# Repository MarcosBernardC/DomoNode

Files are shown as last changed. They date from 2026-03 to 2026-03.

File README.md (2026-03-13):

# DomoNode 🏠⚡






**DomoNode** es un ecosistema IoT de grado industrial diseñado bajo una metodología de desarrollo iterativo. El proyecto escala desde el control de registros en silicio hasta la visualización de datos en la nube, priorizando la eficiencia energética y la documentación técnica rigurosa.

---

## 🏗️ Metodología de Desarrollo (MVP Iterativo)

El progreso del proyecto se documenta a través de reportes técnicos generados en **LuaLaTeX**, vinculando cada iteración con una capa del modelo de sistemas:

### [Iteración 01: System Heartbeat](./research/build/01_heartbeat.pdf) 📄

- **Foco:** Capa 0 (Hardware Core).
- **Hito:** Validación de estabilidad del oscilador interno y secuencia de arranque segura.
- **Resultado:** Consumo optimizado mediante configuración MFINTOSC a 500kHz.
- **🎥 [Ver Demostración](https://youtu.be/Y8ERYFn19mU)**

### [Iteración 02: UART Timing & Telemetry](./research/build/02_uart.pdf) 📄

- **Foco:** Capa 1 y 2 (Física y Enlace).
- **Hito:** Implementación de telemetría serial con error de baudaje del 0.16%.
- **Resultado:** Comunicación robusta a 9600 bps para transmisión de tramas de sensores.
- **🎥 [Ver Demostración](https://youtu.be/vGGgzFn22VY?si=uIu9ADjewPjObTmR)**

---

## 🛠️ Stack Tecnológico

| Dominio | Tecnologías |
| :--- | :--- |
| **Firmware** | Microchip XC8, PIC16F1939, Embedded C |
| **Hardware** | KiCad (Schematic), Proteus/PICSimLab (Simulación) |
| **Infraestructura** | Supabase (PostgreSQL), Koyeb (Deployment) |
| **Documentación** | LuaLaTeX, Inkscape (Vector Graphics) |

---

## 🚀 Alcance del Proyecto

1. **Eficiencia en el Edge:** Algoritmos de bajo consumo para nodos autónomos.
2. **Integración Cloud:** Pipeline de datos real-time desde el microcontrolador al dashboard.
3. **Documentación Técnica:** Manuales de ingeniería con estándares DIN-Minimal.

## Licencia 📄

Este proyecto está bajo la licencia **Attribution-NonCommercial-ShareAlike 4.0 International (CC BY-NC-SA 4.0)**.
Desarrollado por **Marcos Bernard Calixto López**.

---

_Ingeniería Electrónica | Hardware-to-Cloud Integration_

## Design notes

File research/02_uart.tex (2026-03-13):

\documentclass[11pt,a4paper]{article}

% --- Paquetes de Idioma y Tipografía ---
\usepackage[spanish, es-tabla]{babel}
\usepackage{fontspec}
\usepackage{unicode-math}
\usepackage{graphicx}

% --- Layout y Estética ---
\usepackage{amsmath}
\usepackage{booktabs}
\usepackage{geometry}
\usepackage[table]{xcolor} 
\usepackage{microtype}
\usepackage{siunitx}
\usepackage{fancyhdr}
\usepackage{titlesec}
\usepackage{float}

% --- Definición de Colores ---
\definecolor{BLogicNavy}{HTML}{002E5D} 
\definecolor{IndustrialBlue}{HTML}{005EB8}
\definecolor{LightGray}{HTML}{E0E0E0}

% --- Configuración de Fuentes ---
\setmainfont{libertinusserif-regular.otf}[
    BoldFont = libertinusserif-bold.otf,
    ItalicFont = libertinusserif-italic.otf,
    BoldItalicFont = libertinusserif-bolditalic.otf
]
\setmathfont{STIXTwoMath-Regular.otf}
\setmonofont{lmmono10-regular.otf}

\geometry{top=3cm, bottom=3cm, left=2.5cm, right=2.5cm}

% --- Personalización de Títulos (Estética DIN-Minimal) ---
\titleformat{\section}
  {\color{BLogicNavy}\normalfont\Large\bfseries\scshape}
  {\thesection}{1em}{}[\titlerule]

\titleformat{\subsection}
  {\normalfont\large\bfseries}
  {\color{BLogicNavy}\textbullet\ \thesubsection}{1em}{}

% --- Definición de la Fase Actual ---
\newcommand{\faseactual}{MVP: Prototipado Iterativo} 

% --- Pie de Página ---
\pagestyle{fancy}
\fancyhf{}
\renewcommand{\headrulewidth}{0pt}
\renewcommand{\footrulewidth}{0.6pt} 

\fancyfoot[L]{\footnotesize \color{gray} \textbf{DOMONODE} $|$ \faseactual}
\fancyfoot[R]{\footnotesize \color{gray} Página \thepage}

% --- Metadatos PDF ---
\usepackage[pdfauthor={Marcos Bernard Calixto Lopez},
            pdftitle={DomoNode - Iteración 02: UART Timing Validation},
            pdfsubject={Ingeniería Electrónica - UART Analysis},
            pdfkeywords={IoT, PIC16F1939, UART, XC8, MVP},
            pdfstartview={FitH},
            colorlinks=true,
            linkcolor=BLogicNavy,
            urlcolor=IndustrialBlue]{hyperref}

% --- Ruta de búsqueda para imágenes y PDFs ---
\graphicspath{{research/assets/}{assets/}}

\begin{document}

% --- PORTADA DIN-INDUSTRIAL ---
\begin{titlepage}
    \hrule height 2pt
    \vspace{0.4cm}
    
    \begin{flushleft}
        \begin{minipage}[t]{0.60\textwidth}
            {\color{BLogicNavy}\Large\addfontfeatures{LetterSpace=15}\textbf{DOMONODE PROJECT}\par}
            \vspace{0.12cm}
            {\color{gray}\footnotesize\scshape Nodo IoT de Monitoreo Ambiental | Edge Intelligence}
        \end{minipage}
        \begin{minipage}[t]{0.39\textwidth}
            \raggedleft
            {\color{gray}\scriptsize 
            \textbf{FASE} \ $|$ \ \faseactual \\ 
            \textbf{ITERACIÓN} \ $|$ \ 02}
        \end{minipage}
    \end{flushleft}
    
    \vspace{5.5cm}

    \begin{flushleft}
        {\color{gray}\footnotesize\scshape Research \& Hardware Validation}\par
        \vspace{0.25cm}
        {\Huge\addfontfeatures{LetterSpace=2}\textbf{UART Timing \& Telemetry}\par}
        \vspace{0.4cm}
        {\color{BLogicNavy}\hrule height 1.8pt width 11cm} 
        \vspace{0.6cm}
        {\small\textsf{Validación de Capa de Enlace \ $|$ \ Optimización de Consumo}}
    \end{flushleft}

    \vfill

    \begin{flushleft}
        \begin{minipage}{0.5\textwidth}
            \hrule width 3cm
            \vspace{0.3cm}
            {\footnotesize\color{gray}\scshape Responsable del Proyecto}\\
            \vspace{0.15cm}
            \textbf{Marcos Bernard Calixto López}\\
            {\small Ingeniería Electrónica}
        \end{minipage}
    \end{flushleft}

    \vspace{1.5cm}
    
    \hrule height 0.6pt
    \vspace{0.2cm}
    \begin{minipage}[t]{0.65\textwidth}
        {\color{gray}\tiny \textcopyright \ 2026 Marcos Bernard Calixto López. \\ Algunos derechos reservados. Licencia CC BY-NC-SA 4.0.}
    \end{minipage}
    \begin{minipage}[t]{0.34\textwidth}
        \raggedleft
        {\color{gray}\footnotesize Santiago de Surco, \today}
    \end{minipage}
\end{titlepage}

\newpage

% --- CUERPO DEL DOCUMENTO ---

\section{Comunicación: Requerimientos de Telemetría}
Para la evolución del ecosistema \textbf{DomoNode}, se requiere establecer un canal de comunicación asíncrono robusto que permita el envío de tramas de sensores hacia una etapa de agregación. El reto técnico reside en mantener la integridad de los datos operando a una frecuencia de oscilación baja (\SI{500}{\kilo\hertz}) para maximizar la eficiencia energética.

\section{Planificación y Modelado}
En esta segunda iteración, el enfoque se desplaza de la señal de diagnóstico (\textit{Heartbeat}) hacia la \textbf{Capa de Enlace}. Se utiliza el generador de baudios de 16 bits para mitigar errores de cuantización.

\subsection{Análisis de Error ($F_{OSC} = \SI{500}{\kilo\hertz}$)}
Utilizando el modo \texttt{BRG16=1}, se valida matemáticamente la estabilidad a \SI{9600}{bps}:
\begin{equation}
BaudRate = \frac{\SI{500000}{}}{4 \cdot (12 + 1)} = \SI{9615.38}{bps} \implies \text{Error: } \SI{0.16}{\percent}
\end{equation}

\subsection{Asignación de Recursos de Hardware}
\begin{table}[H]
    \centering
    \caption{Especificaciones Técnicas - Iteración 02}
    \vspace{0.2cm}
    \begin{tabular}{@{}llll@{}}
        \toprule
        \textbf{Recurso} & \textbf{Función} & \textbf{Capa} & \textbf{Pin / Valor} \\
        \midrule
        UART TX      & Telemetría Serial   & \textbf{1} (Física) & RC6 (Pin 25) \\
        UART RX      & Comandos/Config     & \textbf{1} (Física) & RC7 (Pin 26) \\
        Baud Rate    & 9600 bps            & \textbf{2} (Enlace) & 0.16\% Error \\
        \bottomrule
    \end{tabular}
\end{table}

\section{Construcción y Validación en Protoboard}
Implementación física para corroborar el análisis matemático previo.

\subsection{Esquemático de Conexión Serial}
Se integra un conversor USB-TTL al nodo \textbf{DomoNode}. Se mantiene el LED de \textit{Heartbeat} en \textbf{RD7} como monitor de estado del sistema durante la transmisión de ráfagas UART.

\begin{figure}[H]
    \centering
    
    \caption{Diagrama de interconexión para validación de telemetría UART.}
    \label{fig:esquema_uart}
\end{figure}

\subsection{Pruebas de Campo e Integración}
El montaje en protoboard valida la ráfaga de datos cada \SI{60}{\second}. Se observa que a \SI{9600}{bps}, el tiempo de ocupación del bus es mínimo (\SI{12.5}{\milli\second}), lo que permite al \textbf{PIC16F1939} retornar a estados de bajo consumo rápidamente.

\begin{figure}[H]
    \centering
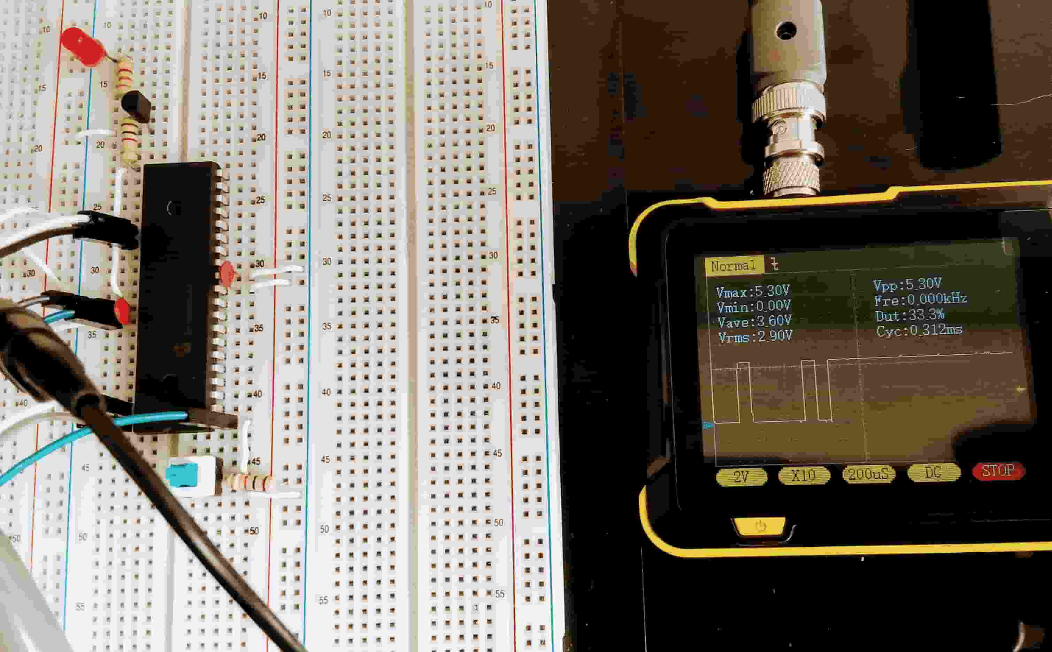
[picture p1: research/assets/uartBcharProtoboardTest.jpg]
    
    \caption{Prototipo físico DomoNode V2: Pruebas de comunicación serial.}
    \label{fig:protoboard_v2}
\end{figure}

\subsection{Resultados del Monitoreo Digital}
La validación del flujo de datos se realizó mediante el software de monitoreo industrial \textbf{HTerm} sobre la distribución \textbf{Fedora}. Se confirmó la recepción íntegra del testigo de transmisión (\textit{testigo 'B'}) con una periodicidad de \SI{1}{\second}.

\begin{figure}[H]
    \centering
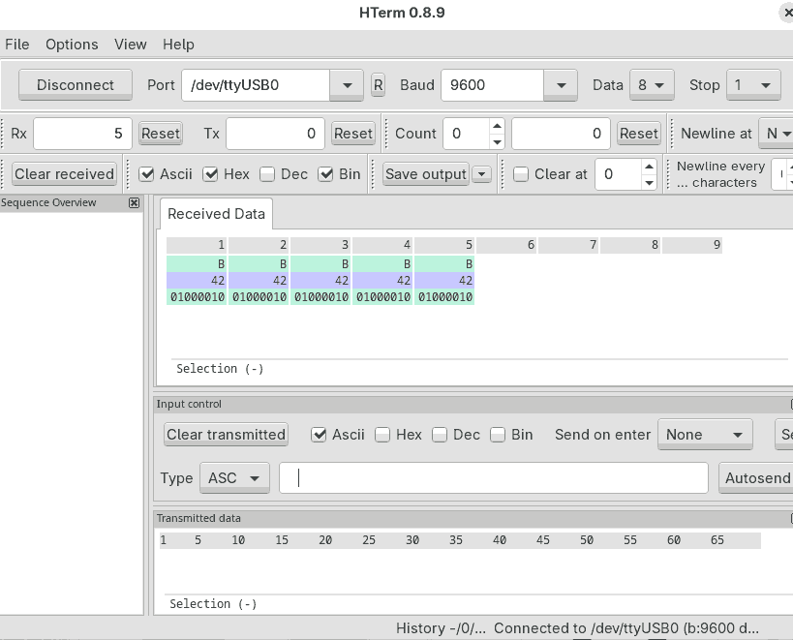
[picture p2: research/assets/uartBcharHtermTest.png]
    
    \caption{Monitoreo multiformato en HTerm: Validación del testigo de transmisión. Se observa la consistencia entre el carácter ASCII 'B', su valor hexadecimal (0x42) y su representación binaria, confirmando la estabilidad del baudaje a \SI{500}{\kilo\hertz}.}
    \label{fig:hterm_success}
\end{figure}

\vspace{0.3cm}
\noindent\textbf{Demostración en video:} 
\href{https://youtu.be/vGGgzFn22VY?si=uIu9ADjewPjObTmR}{DomoNode Iteración 02 - Validación UART \& Timing}

\section{Conclusiones de la Iteración 02}
La validación física confirma que la configuración de 16 bits del BRG permite una comunicación fiable incluso a frecuencias de reloj reducidas. 
\begin{itemize}
    \item \textbf{Resultado:} Error de baudaje dentro de los límites industriales ($<\SI{2}{\percent}$).
    \item \textbf{Próximo Paso:} Integración del sensor de temperatura/humedad para generar tramas de datos reales en la Iteración 03.
\end{itemize}

\end{document}

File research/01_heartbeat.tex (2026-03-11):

\documentclass[11pt,a4paper]{article}

% --- Paquetes de Idioma y Tipografía ---
\usepackage[spanish, es-tabla]{babel}
\usepackage{fontspec}
\usepackage{unicode-math}
\usepackage{graphicx}

% --- Layout y Estética ---
\usepackage{amsmath}
\usepackage{booktabs}
\usepackage{geometry}
\usepackage[table]{xcolor} 
\usepackage{microtype}
\usepackage{siunitx}
\usepackage{fancyhdr}
\usepackage{titlesec}
\usepackage{float}

% --- Definición de Colores ---
\definecolor{BLogicNavy}{HTML}{002E5D} 
\definecolor{IndustrialBlue}{HTML}{005EB8}
\definecolor{LightGray}{HTML}{E0E0E0}

% --- Configuración de Fuentes ---
\setmainfont{libertinusserif-regular.otf}[
    BoldFont = libertinusserif-bold.otf,
    ItalicFont = libertinusserif-italic.otf,
    BoldItalicFont = libertinusserif-bolditalic.otf
]
\setmathfont{STIXTwoMath-Regular.otf}
\setmonofont{lmmono10-regular.otf}

\geometry{top=3cm, bottom=3cm, left=2.5cm, right=2.5cm}

% --- Personalización de Títulos (Estética DIN-Minimal) ---
\titleformat{\section}
  {\color{BLogicNavy}\normalfont\Large\bfseries\scshape}
  {\thesection}{1em}{}[\titlerule]

\titleformat{\subsection}
  {\normalfont\large\bfseries}
  {\color{BLogicNavy}\textbullet\ \thesubsection}{1em}{}

% --- Definición de la Fase Actual ---
\newcommand{\faseactual}{MVP: Prototipado Iterativo} 

% --- Pie de Página Coherente con Portada ---
\pagestyle{fancy}
\fancyhf{}
\renewcommand{\headrulewidth}{0pt}
\renewcommand{\footrulewidth}{0.6pt} 

\fancyfoot[L]{\footnotesize \color{gray} \textbf{B-LOGIC NODES} $|$ \faseactual}
\fancyfoot[R]{\footnotesize \color{gray} Página \thepage}

% --- Metadatos y Protección Digital (CORREGIDO) ---
\usepackage[pdfauthor={Marcos Bernard Calixto Lopez},
            pdftitle={DomoNode - System Heartbeat Validation},
            pdfsubject={Ingeniería Electrónica - Capa 0},
            pdfkeywords={IoT, PIC16F1939, B-Logic Nodes},
            pdfstartview={FitH}, % Ajusta el zoom al ancho de la página al abrir
            colorlinks=true,
            linkcolor=BLogicNavy,
            urlcolor=IndustrialBlue]{hyperref}

\usepackage{pdfpages} % Para insertar páginas PDF completas

% --- Ruta de búsqueda para imágenes y PDFs ---
\graphicspath{{research/assets/}{assets/}}

\begin{document}

% --- PORTADA DIN-INDUSTRIAL CON PROTECCIÓN DE AUTOR ---
\begin{titlepage}
    \hrule height 2pt
    \vspace{0.4cm}
    
    \begin{flushleft}
        \begin{minipage}[t]{0.60\textwidth}
            {\color{BLogicNavy}\Large\addfontfeatures{LetterSpace=15}\textbf{B-LOGIC NODES}\par}
            \vspace{0.12cm}
            {\color{gray}\footnotesize\scshape IoT Node Framework | Hardware-to-Cloud Integration}
        \end{minipage}
        \begin{minipage}[t]{0.39\textwidth}
            \raggedleft
            {\color{gray}\scriptsize 
            \textbf{FASE} \ $|$ \ \faseactual \\ 
            \textbf{ITERACIÓN} \ $|$ \ 01}
        \end{minipage}
    \end{flushleft}
    
    \vspace{5.5cm}

    \begin{flushleft}
        {\color{gray}\footnotesize\scshape DomoNode Ecosystem}\par
        \vspace{0.25cm}
        {\Huge\addfontfeatures{LetterSpace=2}\textbf{System Heartbeat Validation}\par}
        \vspace{0.4cm}
        {\color{BLogicNavy}\hrule height 1.8pt width 11cm} 
        \vspace{0.6cm}
        {\small\textsf{Firmware Design \ $|$ \ Layer 0}}
    \end{flushleft}

    \vfill

    \begin{flushleft}
        \begin{minipage}{0.5\textwidth}
            \hrule width 3cm
            \vspace{0.3cm}
            {\footnotesize\color{gray}\scshape Responsable del Proyecto}\\
            \vspace{0.15cm}
            \textbf{Marcos Bernard Calixto López}\\
            {\small Ingeniería Electrónica}
        \end{minipage}
    \end{flushleft}

    \vspace{1.5cm}
    
    % Pie de página de la portada: Protección y Ubicación
    \hrule height 0.6pt
    \vspace{0.2cm}
    \begin{minipage}[t]{0.65\textwidth}
        {\color{gray}\tiny \textcopyright \ 2026 Marcos Bernard Calixto López. \\ Algunos derechos reservados. Licencia CC BY-NC-SA 4.0.}
    \end{minipage}
    \begin{minipage}[t]{0.34\textwidth}
        \raggedleft
        {\color{gray}\footnotesize Santiago de Surco, \today}
    \end{minipage}
\end{titlepage}

\newpage

% --- CUERPO DEL DOCUMENTO ---

\section{Comunicación: Requerimientos y Alcance}
Para el nodo \textbf{DomoNode}, se ha identificado la necesidad de una señal de diagnóstico de bajo nivel (\textit{Heartbeat}). El sistema requiere una validación visual inmediata tras un evento de \textit{Master Clear} (MCLR) que confirme la estabilidad del oscilador interno antes de iniciar procesos de mayor complejidad.

\section{Planificación Rápida}
En esta etapa del \textbf{\faseactual}, el sprint de diseño se centra en la \textbf{Capa 0 (Hardware Core)}, estableciendo los cimientos para las capas superiores del modelo OSI mediante los siguientes objetivos:
\begin{itemize}
    \setlength{\itemsep}{2pt}
    \item Selección de un pin de salida dedicado exclusivamente a diagnóstico visual.
    \item Configuración del oscilador interno (\texttt{INTOSC}) para minimizar el BOM (\textit{Bill of Materials}).
    \item Definición de una secuencia de inicio que diferencie el estado de arranque de la ejecución normal.
\end{itemize}

\section{Modelado y Diseño Rápido}
Diseño orientado al microcontrolador \textbf{PIC16F1939}. El enfoque iterativo permite definir constantes físicas reutilizables en versiones superiores.
Este diseño se estructura desde la configuración del silicio (\textbf{Capa 0}), garantizando que los registros fundamentales (Fuses y Clock Tree) operen dentro de los márgenes nominales antes de la ejecución del firmware de aplicación.

\subsection{Capa 0: Configuración de Base de Tiempo}
Se selecciona el bloque \textbf{MFINTOSC} a \SI{500}{\kilo\hertz}. El modelado de tiempos en el nivel de registros se rige por:
\begin{equation}
F_{CY} = \frac{F_{OSC}}{4} \implies \frac{\SI{500}{\kilo\hertz}}{4} = \SI{125}{\kilo\hertz} \implies T_{CY} = \SI{8}{\micro\second}
\end{equation}

\subsection{Capa Física: Asignación de Recursos (I/O Mapping)}
\begin{table}[H]
    \centering
    \caption{Especificaciones Técnicas de la Iteración 01}
    \vspace{0.2cm}
    \begin{tabular}{@{}llll@{}}
        \toprule
        \textbf{Recurso} & \textbf{Función} & \textbf{Capa} & \textbf{Pin / Valor} \\
        \midrule
        System Clock & Internal Oscillator & \textbf{0} (Register) & 0x68 (500kHz) \\
        Indicator LED & Heartbeat Status    & \textbf{1} (Electrical) & RD7 (Pin 30) \\
        Reset Vector  & MCLR Logic          & \textbf{0} (Fuse)      & Pin 1 (RE3)  \\
        \bottomrule
    \end{tabular}
\end{table}

\subsection{Esquemático del Módulo de Validación}
Como se observa en la Figura~\ref{fig:esquema_v1}, se implementa una etapa de potencia con un transistor NPN para el control del LED, desacoplo de alimentación y un nodo de reset físico mediante el pin MCLR.

\begin{figure}[H]
    \centering
    
    \caption{Diseño de hardware para la validación del System Heartbeat (Capa Física).}
    \label{fig:esquema_v1}
\end{figure}

\section{Construcción del Prototipo}
Implementación física y carga de firmware.

\subsection{Firmware (XC8)}
Se implementa la lógica de control en C utilizando el compilador XC8. El código establece el \textit{Heartbeat} mediante retardos bloqueantes de \SI{500}{\milli\second}, precedidos por una ráfaga de inicio para validación de \textit{Power-on Reset}. El firmware final para producción utiliza la configuración \texttt{MFINTOSC} a \SI{500}{\kilo\hertz} para optimizar la eficiencia energética del nodo.

\subsection{Montaje en Protoboard}
El circuito fue ensamblado sobre protoboard siguiendo el esquemático de la Figura~\ref{fig:esquema_v1}. La alimentación se suministró desde el bus de \SI{5}{\volt} del programador PICKit2 vía ICSP, sin fuente externa adicional en esta iteración.

\begin{figure}[H]
    \centering
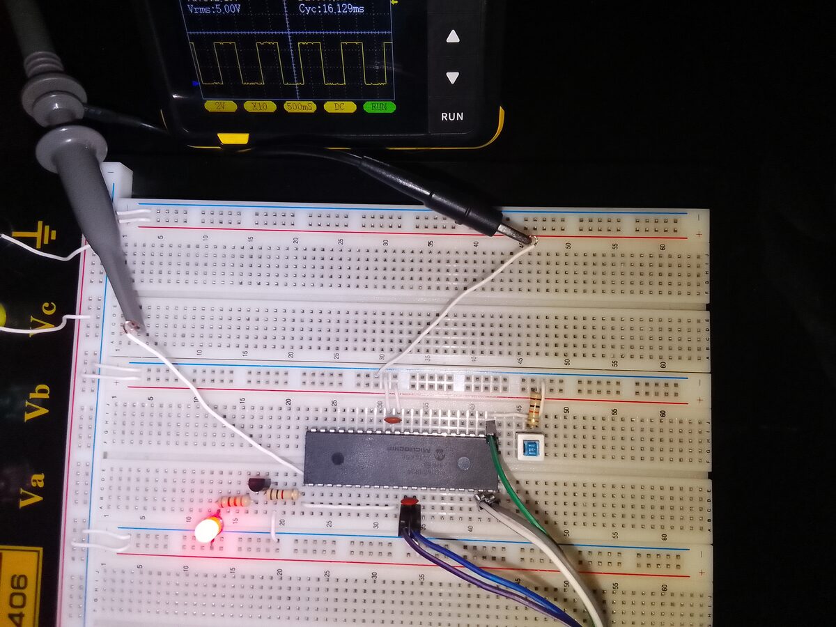
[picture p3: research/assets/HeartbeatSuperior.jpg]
    
    \caption{Montaje físico del DomoNode V1 en protoboard — Iteración 01.}
    \label{fig:protoboard}
\end{figure}

La validación en hardware real confirmó el comportamiento simulado: el LED conectado a \textbf{RD7 (Pin~30)} oscila a \SI{1}{\hertz} con un \textit{duty cycle} del 50\%, precedido por la ráfaga de inicio que distingue el arranque de la ejecución normal.

\vspace{0.3cm}
\noindent\textbf{Demostración en video:} 
\href{https://youtu.be/Y8ERYFn19mU}{DomoNode Heartbeat V1 - Validación de Sistema}

\section{Despliegue y Entrega (Pruebas)}

\subsection{Entorno de Simulación y Ajustes Técnicos}
Para la validación funcional se utilizó \textbf{PICSimLab v0.9.2} emulando una placa \textit{McLab2}. Durante las pruebas iniciales, se identificó una limitación en el paso de tiempo del simulador al operar por debajo de \SI{1}{\mega\hertz}. Para garantizar una correlación 1:1 con el tiempo real en el osciloscopio virtual, se optó por una \textbf{estrategia de ajuste de validación}:
\begin{itemize}
    \setlength{\itemsep}{2pt}
    \item Se reconfiguró el registro \texttt{OSCCON} a \texttt{0x30} (\SI{1}{\mega\hertz}).
    \item Se actualizó la macro \texttt{\_XTAL\_FREQ} a \SI{1}{\mega\hertz} para resincronizar los retardos.
\end{itemize}

\subsection{Resultados en Osciloscopio}
Tras el ajuste, el análisis de señales (Figura~\ref{fig:osciloscopio}) confirmó la precisión del firmware:
\begin{itemize}
    \setlength{\itemsep}{2pt}
    \item \textbf{Ciclo Completo:} \SI{1000.000}{\milli\second} (Exactitud del 100\% en simulación).
    \item \textbf{Duty Cycle:} 50\%, con semiciclos de \SI{500}{\milli\second}.
\end{itemize}

\begin{figure}[H]
    \centering
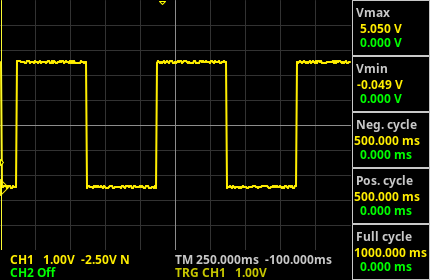
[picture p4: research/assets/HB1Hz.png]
    
    \caption{Validación del Heartbeat a 1Hz en osciloscopio virtual.}
    \label{fig:osciloscopio}
\end{figure}

\section{Retroalimentación (Feedback)}
La Iteración 01 valida con éxito la estabilidad de la \textbf{Capa 0}. Como puntos clave para la Iteración 02 se definen:
\begin{itemize}
    \setlength{\itemsep}{2pt}
    \item \textbf{Optimización Energética:} Retornar a la frecuencia de \SI{500}{\kilo\hertz} en el prototipo físico para reducir el consumo de corriente dinámico.
    \item \textbf{Escalabilidad:} Implementar el manejo del LCD para mostrar estados de red, utilizando los tiempos de instrucción ya validados en esta fase.
\end{itemize}
\end{document}

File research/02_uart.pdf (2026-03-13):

## D O M O N O D E P R O J E C T

Nodo IoT de Monitoreo Ambiental | Edge Intelligence
FASE | MVP: Prototipado Iterativo
ITERACIÓN | 02

Research & Hardware Validation

# UART Timing & Telemetry

Validación de Capa de Enlace | Optimización de Consumo

Responsable del Proyecto
Marcos Bernard Calixto López Ingeniería Electrónica

© 2026 Marcos Bernard Calixto López.

Algunos derechos reservados. Licencia CC BY-NC-SA 4.0.

Santiago de Surco, 13 de marzo de 2026

## 1 Comunicación: Requerimientos de Telemetría

Para la evolución del ecosistema DomoNode, se requiere establecer un canal de comunicación asíncrono robusto que permita el envío de tramas de sensores hacia una etapa de agregación. El reto técnico reside en mantener la integridad de los datos operando a una frecuencia de oscilación baja (500 kHz) para maximizar la eficiencia energética.

## 2 Planificación y Modelado

En esta segunda iteración, el enfoque se desplaza de la señal de diagnóstico (Heartbeat) hacia la Capa de Enlace. Se utiliza el generador de baudios de 16 bits para mitigar errores de cuantización.

- 2.1 Análisis de Error (FOSC = 500 kHz)
Utilizando el modo BRG16=1, se valida matemáticamente la estabilidad a 9600 bps:

BaudRate = 500 000
4 ⋅ (12 + 1) = 9615,38 bps ⟹ Error: 0,16 % | (1)
- 2.2 Asignación de Recursos de Hardware

Tabla 1: Especificaciones Técnicas - Iteración 02

Recurso | Función | Capa | Pin / Valor
UART TX Telemetría Serial | 1 (Física) | RC6 (Pin 25)
UART RX Comandos/Config 1 (Física) | RC7 (Pin 26)
Baud Rate 9600 bps | 2 (Enlace) 0.16 % Error

## 3 Construcción y Validación en Protoboard

Implementación física para corroborar el análisis matemático previo.

- 3.1 Esquemático de Conexión Serial
Se integra un conversor USB-TTL al nodo DomoNode. Se mantiene el LED de Heartbeat en RD7 como monitor de estado del sistema durante la transmisión de ráfagas UART.

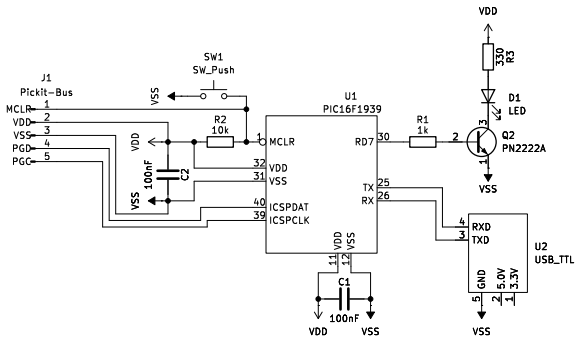
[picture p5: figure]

Figura 1: Diagrama de interconexión para validación de telemetría UART.

DOMONODE | MVP: Prototipado Iterativo | Página 1

- 3.2 Pruebas de Campo e Integración
El montaje en protoboard valida la ráfaga de datos cada 60 s. Se observa que a 9600 bps, el tiempo de ocupación del bus es mínimo (12,5 ms), lo que permite al PIC16F1939 retornar a estados de bajo consumo rápidamente.


Figura 2: Prototipo físico DomoNode V2: Pruebas de comunicación serial.

- 3.3 Resultados del Monitoreo Digital
La validación del flujo de datos se realizó mediante el software de monitoreo industrial HTerm sobre la distribución Fedora. Se confirmó la recepción íntegra del testigo de transmisión (testigo ’B’) con una periodicidad de 1 s.


Figura 3: Monitoreo multiformato en HTerm: Validación del testigo de transmisión. Se observa la consistencia entre el carácter ASCII ’B’, su valor hexadecimal (0x42) y su representación binaria, confirmando la estabilidad del baudaje a 500 kHz.

Demostración en video: DomoNode Iteración 02 - Validación UART & Timing (https://youtu.be/vGGgzFn22VY?si=uIu9ADjewPjObTmR)

DOMONODE | MVP: Prototipado Iterativo | Página 2

## 4 Conclusiones de la Iteración 02

La validación física confirma que la configuración de 16 bits del BRG permite una comunicación fiable incluso a frecuencias de reloj reducidas.

Resultado: Error de baudaje dentro de los límites industriales (< 2 %).

Próximo Paso: Integración del sensor de temperatura/humedad para generar tramas de datos reales en la Iteración 03.

DOMONODE | MVP: Prototipado Iterativo | Página 3

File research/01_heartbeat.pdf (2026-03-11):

## B - L O G I C N O D E S

IoT Node Framework | Hardware-to-Cloud Integration
FASE | MVP: Prototipado Iterativo
ITERACIÓN | 01

DomoNode Ecosystem

# System Heartbeat Validation

Firmware Design | Layer 0

Responsable del Proyecto
Marcos Bernard Calixto López Ingeniería Electrónica

© 2026 Marcos Bernard Calixto López.

Algunos derechos reservados. Licencia CC BY-NC-SA 4.0.

Santiago de Surco, 11 de marzo de 2026

## 1 Comunicación: Requerimientos y Alcance

Para el nodo DomoNode, se ha identificado la necesidad de una señal de diagnóstico de bajo nivel (Heartbeat). El sistema requiere una validación visual inmediata tras un evento de Master Clear (MCLR) que confirme la estabilidad del oscilador interno antes de iniciar procesos de mayor complejidad.

## 2 Planificación Rápida

En esta etapa del MVP: Prototipado Iterativo, el sprint de diseño se centra en la Capa 0 (Hardware Core), estableciendo los cimientos para las capas superiores del modelo OSI mediante los siguientes objetivos:

Selección de un pin de salida dedicado exclusivamente a diagnóstico visual.
Configuración del oscilador interno (INTOSC) para minimizar el BOM (Bill of Materials). Definición de una secuencia de inicio que diferencie el estado de arranque de la ejecución normal.

## 3 Modelado y Diseño Rápido

Diseño orientado al microcontrolador PIC16F1939. El enfoque iterativo permite definir constantes físicas reutilizables en versiones superiores. Este diseño se estructura desde la configuración del silicio (Capa 0), garantizando que los registros fundamentales (Fuses y Clock Tree) operen dentro de los márgenes nominales antes de la ejecución del firmware de aplicación.

- 3.1 Capa 0: Configuración de Base de Tiempo
Se selecciona el bloque MFINTOSC a 500 kHz. El modelado de tiempos en el nivel de registros se rige por:

FCY =

FOSC
4 ⟹

500 kHz
4
= 125 kHz ⟹ TCY = 8 µs | (1)
- 3.2 Capa Física: Asignación de Recursos (I/O Mapping)

Tabla 1: Especificaciones Técnicas de la Iteración 01

Recurso | Función | Capa | Pin / Valor
System Clock Internal Oscillator 0 (Register) | 0x68 (500kHz)
Indicator LED Heartbeat Status | 1 (Electrical) RD7 (Pin 30)
Reset Vector | MCLR Logic | 0 (Fuse) | Pin 1 (RE3)
- 3.3 Esquemático del Módulo de Validación
Como se observa en la Figura 1, se implementa una etapa de potencia con un transistor NPN para el control del LED, desacoplo de alimentación y un nodo de reset físico mediante el pin MCLR.
B-LOGIC NODES | MVP: Prototipado Iterativo | Página 1

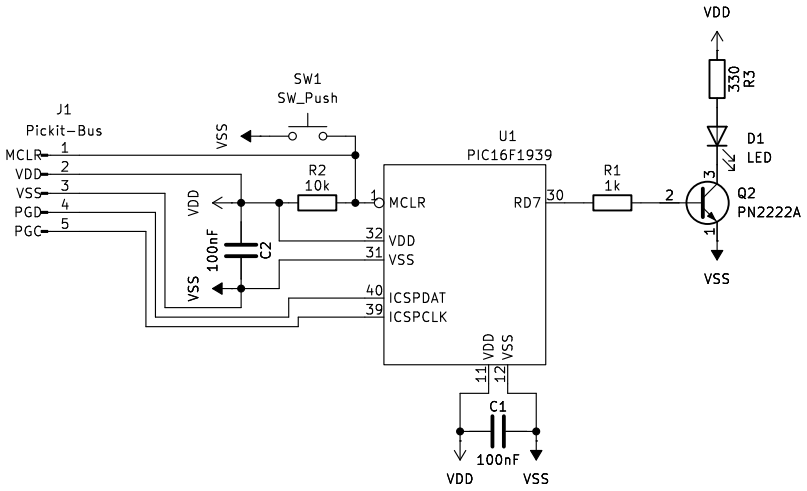
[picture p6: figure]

Figura 1: Diseño de hardware para la validación del System Heartbeat (Capa Física).

## 4 Construcción del Prototipo

Implementación física y carga de firmware.

- 4.1 Firmware (XC8)
Se implementa la lógica de control en C utilizando el compilador XC8. El código establece el Heartbeat mediante retardos bloqueantes de 500 ms, precedidos por una ráfaga de inicio para validación de Power-on Reset. El firmware final para producción utiliza la configuración MFINTOSC a 500 kHz para optimizar la eficiencia energética del nodo.
- 4.2 Montaje en Protoboard
El circuito fue ensamblado sobre protoboard siguiendo el esquemático de la Figura 1. La alimentación se suministró desde el bus de 5 V del programador PICKit2 vía ICSP, sin fuente externa adicional en esta iteración.


Figura 2: Montaje físico del DomoNode V1 en protoboard — Iteración 01.

B-LOGIC NODES | MVP: Prototipado Iterativo | Página 2

La validación en hardware real confirmó el comportamiento simulado: el LED conectado a RD7 (Pin 30) oscila a 1 Hz con un duty cycle del 50 %, precedido por la ráfaga de inicio que distingue el arranque de la ejecución normal.

Demostración en video: DomoNode Heartbeat V1 - Validación de Sistema (https://youtu.be/Y8ERYFn19mU)

## 5 Despliegue y Entrega (Pruebas)

- 5.1 Entorno de Simulación y Ajustes Técnicos
Para la validación funcional se utilizó PICSimLab v0.9.2 emulando una placa McLab2. Durante las pruebas iniciales, se identificó una limitación en el paso de tiempo del simulador al operar por debajo de 1 MHz. Para garantizar una correlación 1:1 con el tiempo real en el osciloscopio virtual, se optó por una estrategia de ajuste de validación:
Se reconfiguró el registro OSCCON a 0x30 (1 MHz).
Se actualizó la macro _XTAL_FREQ a 1 MHz para resincronizar los retardos.
- 5.2 Resultados en Osciloscopio
Tras el ajuste, el análisis de señales (Figura 3) confirmó la precisión del firmware: Ciclo Completo: 1000,000 ms (Exactitud del 100 % en simulación).
Duty Cycle: 50 %, con semiciclos de 500 ms.


Figura 3: Validación del Heartbeat a 1Hz en osciloscopio virtual.

## 6 Retroalimentación (Feedback)

La Iteración 01 valida con éxito la estabilidad de la Capa 0. Como puntos clave para la Iteración 02 se definen:
Optimización Energética: Retornar a la frecuencia de 500 kHz en el prototipo físico para reducir el consumo de corriente dinámico.
Escalabilidad: Implementar el manejo del LCD para mostrar estados de red, utilizando los tiempos de instrucción ya validados en esta fase.
B-LOGIC NODES | MVP: Prototipado Iterativo | Página 3

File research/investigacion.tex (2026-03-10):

\documentclass[journal,10pt]{IEEEtran}

% --- Paquetes de Estética Superior ---
\usepackage[spanish,es-nodecimaldot]{babel}
\usepackage{fontspec} 
\usepackage{microtype} % Optimiza el espaciado entre letras y palabras

% Fuentes del sistema (Modernas y abiertas)
\setmainfont{Latin Modern Roman}[Scale=1.05] % Un poco más grande para evitar lo "chico"
\setsansfont{Roboto}
\setmonofont{Fira Code} 

% --- Control de "Achatamiento" ---
\linespread{1.15} % El interlineado que IEEE odia pero nosotros amamos
\setlength{\parskip}{0.5ex plus 0.2ex minus 0.2ex} % Espacio entre párrafos

\usepackage{graphicx}
\usepackage[hidelinks]{hyperref}
\usepackage{xcolor}

% --- Parche de Seguridad ---
\makeatletter
\ifx\IEEEPARSTART\undefined
  \newcommand{\IEEEPARSTART}[2]{{\large\sffamily\textbf{#1}}#2}
\fi
\makeatother

\graphicspath{{research/assets/}{assets/}} 

% --- Encabezado Moderno ---
\makeatletter
\def\ps@IEEEtitlepagestyle{
  \def\@oddhead{\parbox{\textwidth}{
    \vspace{0cm}
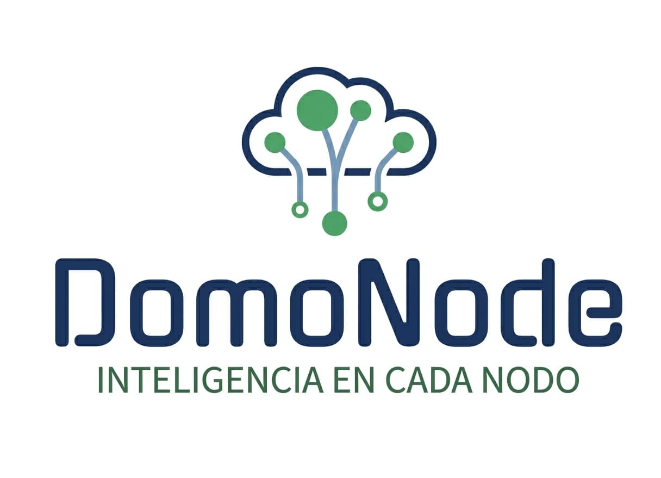
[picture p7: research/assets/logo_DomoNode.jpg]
     
    \hfill 
    \small\sffamily\itshape Proyecto DomoNode | Reporte Técnico v1.0
    \vspace{0.6cm}
  }}%
  \def\@evenhead{}
}
\makeatother

\begin{document}

\title{\sffamily Nodos IoT basados en PIC16F1939: Arquitectura DomoNode}

\author{Marcos Bernard Calixto López,~\IEEEmembership{Ingeniero Electrónico}%
\thanks{Desarrollo integral bajo Fedora Linux y compilador XC8.}}

\maketitle
\thispagestyle{IEEEtitlepagestyle}

\begin{abstract}
% El resumen ahora con Sans Serif y más aire
{\sffamily\fontsize{9.5pt}{12pt}\selectfont
Este documento técnico presenta la implementación del ecosistema \textbf{DomoNode}. Se detalla el flujo de trabajo bajo \textbf{Fedora Linux}, el uso de compiladores \textbf{XC8} y la integración de servicios en la nube como \textbf{Koyeb} y \textbf{Supabase} para evitar el \textit{cold start}. El objetivo es demostrar que la documentación técnica de alta fidelidad y bajo peso (34.4 kB) es un estándar de calidad en la ingeniería moderna.}
\end{abstract}

\begin{IEEEkeywords}
{\sffamily Sistemas Embebidos, PIC12F675, IoT, LaTeX, Cloud Computing.}
\end{IEEEkeywords}

\section{\sffamily Introducción}
\IEEEPARSTART{E}{l} desarrollo de sistemas domóticos requiere una simbiosis entre el hardware de bajo nivel y el software de gestión. DomoNode utiliza microcontroladores de 8 bits para tareas atómicas, garantizando eficiencia energética y robustez.

\section{\sffamily Conclusión}
La estandarización bajo el formato IEEE con tipografía moderna permite una comunicación clara de los avances técnicos, facilitando la integración en portafolios profesionales.

\begin{thebibliography}{1}
\bibitem{domo1}
M. B. Calixto López, ``Proyecto DomoNode: Especificaciones v1.0,'' 2026.
\end{thebibliography}

\end{document}

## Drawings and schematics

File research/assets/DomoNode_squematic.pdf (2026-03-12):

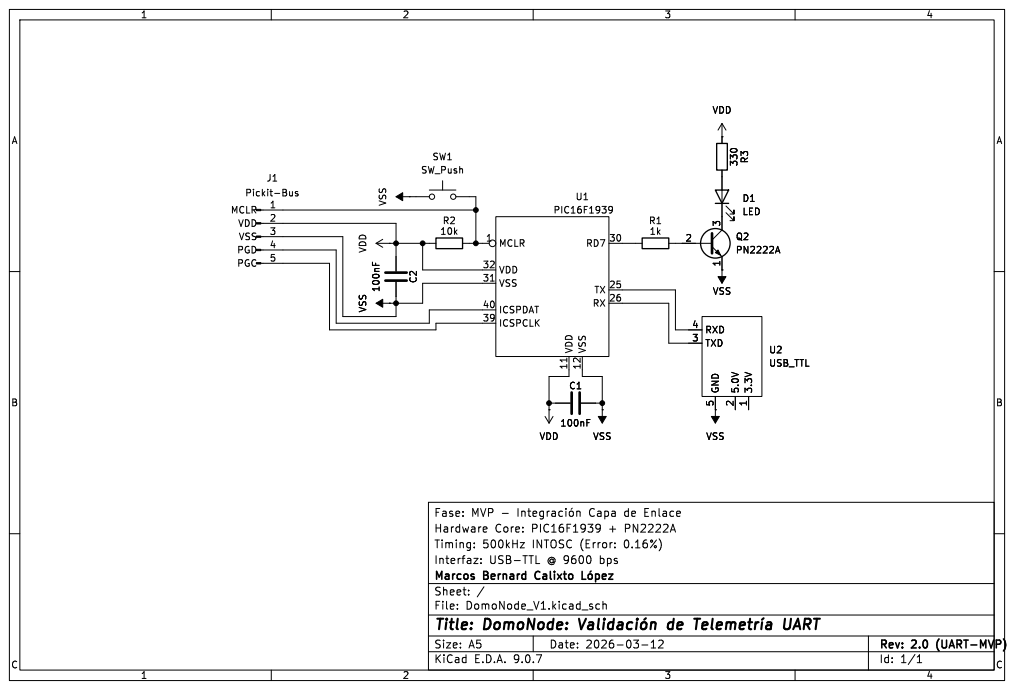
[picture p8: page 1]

10k SW1 SW_Push MCLR 1 VDD 2 VSS 3 PGD 4 PGC 5

Id: 1/1 Title: DomoNode: þÿValidación de þÿTelemetría UART

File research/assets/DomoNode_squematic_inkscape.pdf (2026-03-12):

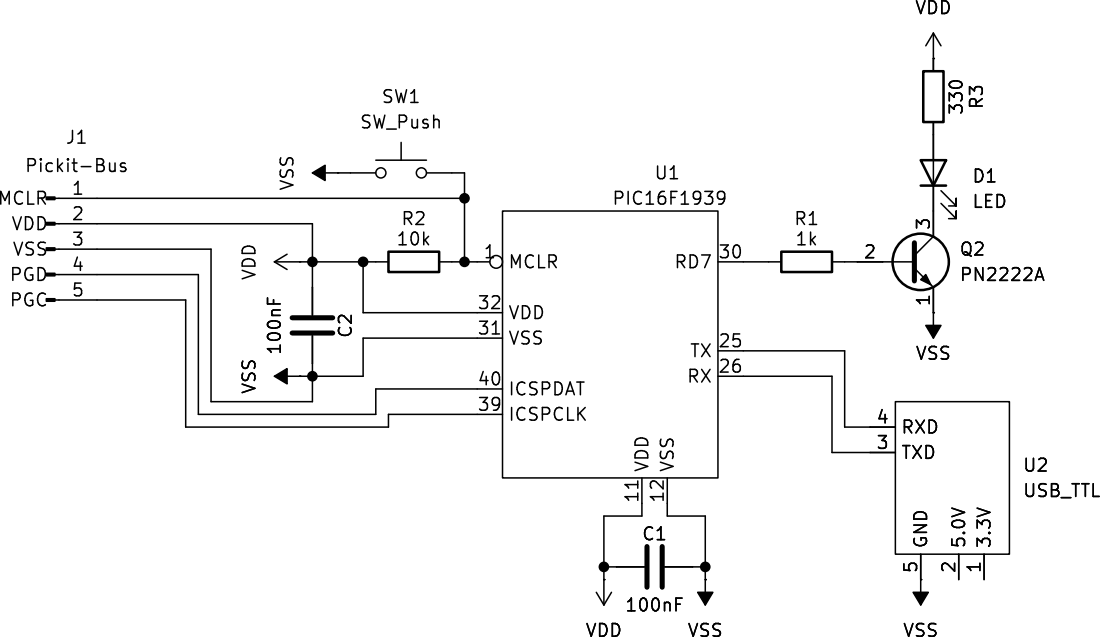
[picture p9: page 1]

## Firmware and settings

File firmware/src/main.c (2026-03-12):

/*
 * File:   main.c
 * Author: Marcos Bernard Calixto López
 * Project: DomoNode - Iteration 02: UART Validation
 */

#include <xc.h>

// --- CONFIGURACIÓN DE FUSES (Indispensable para que el compilador sepa el target) ---
#pragma config FOSC = INTOSC, WDTE = OFF, PWRTE = ON, MCLRE = ON, CP = OFF, BOREN = ON, CLKOUTEN = OFF, IESO = OFF, FCMEN = OFF

#define _XTAL_FREQ 500000 

// Mapeo de Hardware
#define HEARTBEAT_LED LATDbits.LATD7
#define HEARTBEAT_TRIS TRISDbits.TRISD7

// Prototipos de funciones propias (Capa 0)
void system_init(void);
void uart_init(void);
void uart_putc(char c);

void uart_init(void) {
    // Configuración de pines para UART
    TRISCbits.TRISC6 = 1; 
    TRISCbits.TRISC7 = 1; 

    // Baud Rate: 9600 bps @ 500kHz
    BAUDCONbits.BRG16 = 1; 
    TXSTAbits.BRGH = 1;    
    SPBRGL = 12;           
    SPBRGH = 0;

    TXSTAbits.SYNC = 0;    
    RCSTAbits.SPEN = 1;    
    TXSTAbits.TXEN = 1;    
}

void uart_putc(char c) {
    while(!PIR1bits.TXIF); 
    TXREG = c;             
}

void system_init(void) {
    OSCCON = 0x38;          // 500kHz
    ANSELD = 0;             
    // ANSELC = 0;             // ¡Importante para UART! ¡No existe para el PIC16F1939!
    HEARTBEAT_TRIS = 0;     
    HEARTBEAT_LED = 0;      
    uart_init();
}

void main(void) {
    system_init();
    
    while(1) {
        HEARTBEAT_LED = 1;
        uart_putc('B');    // Enviamos el testigo 'B'
        __delay_ms(500); 
        
        HEARTBEAT_LED = 0;
        __delay_ms(500);
    }
}

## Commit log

2026-03-07 feat: inicializar arquitectura base de DomoNode
    Se establece la estructura de directorios para firmware, investigación y hardware.
    Incluye el Makefile optimizado para XC8 v2.40 en Fedora y el archivo base main.c.
    Se configura el .gitignore para excluir archivos binarios y temporales de compilación.
2026-03-07 feat: establecer flujo de trabajo protegido y sistema de documentación
    Se configura .gitignore para preservar PDFs finales mientras se ignoran binarios de XC8 y temporales de LaTeX.
    Se implementa Makefile con reglas de limpieza atómica (clean-firmware, clean-research) para evitar pérdida de datos.
    Se habilita el soporte para múltiples archivos .tex mediante detección dinámica en la carpeta research/.
2026-03-07 chore: actualizar reglas de compilación para lualatex y directorios de build
2026-03-07 chore: configurar gitignore para proteger propiedad intelectual de fuentes LaTeX
2026-03-07 docs: remover fuente LaTeX del rastreo para proteger propiedad intelectual
2026-03-09 docs(research): agregar reporte de validación del sistema (heartbeat)
2026-03-09 docs(research): actualizar reporte de heartbeat con marca B-Logic Nodes y ajustes de estilo
2026-03-09 research(01_heartbeat.tex): finalizar etapa de modelado y diseño rápido para Iteración 01
2026-03-09 docs: migrar reporte de investigación a formato DIN-Industrial
    - Reestructuración completa del documento usando LaTeX (clase article).
    - Implementación de portada minimalista estilo B-Logic Nodes.
    - Estandarización de secciones según el flujo: Comunicación -> Plan -> Modelado.
    - Definición formal de la "Capa 0" para configuración de silicio (PIC16F1939).
    - Actualización de ecuaciones técnicas con soporte siunitx.
2026-03-09 docs: finalizar plantilla de reporte técnico y corregir metadatos de hyperref
    - Se establece la estructura definitiva del reporte basada en Prototipado Iterativo.
    - Corrección de error en el paquete hyperref (eliminación de pdfcopyright).
    - Inclusión de metadatos PDF para protección de autoría.
    - Sincronización de estética DIN-Industrial entre portada y pie de página.
    - Flujo metodológico blindado: Comunicación -> Plan -> Modelado -> Construcción.
2026-03-10 chore: actualizar gitignore para archivos de diseño y compilación
2026-03-10 feat(hw): añadir esquemático DomoNode V1 y archivos de exportación
    [DomoNode_V1.kicad_pcb, DomoNode_V1.kicad_sch]
2026-03-10 docs(research): implementar validación de heartbeat y estructura de capas
2026-03-10 feat(hw): configurar proyecto base de KiCad para DomoNode V1
2026-03-10 feat(fw): ajustar reloj a 1MHz y documentar validación de Capa 0
2026-03-10 docs: integrar pinout detallado de PN2222A y corregir diagramas en DomoNode V1
2026-03-10 docs: actualizar esquema de KiCad con numeración de pines y documentación de hardware
    [DomoNode_V1.kicad_sch]
2026-03-10 hardware: integrar puerto de programación ICSP para PICkit3 en el esquema principal
    [DomoNode_V1.kicad_sch]
2026-03-10 docs: actualizar reporte heartbeat con esquemático de bus ICSP y assets de diseño
2026-03-11 docs(heartbeat): complete section 4.2 with protoboard evidence
    - Add HeartbeatSuperior.jpg (optimized, EXIF stripped)
    - Section 4.2: physical assembly description and figure
    - Demo video link left as pending (editing in progress)
    - Rebuild PDF with updated content
2026-03-11 docs(heartbeat): fix figure placement and compact spacing
    - Replace [!ht] with [H] on all figures (float package)
    - Add itemsep=2pt to all itemize environments
    - Tighten vspace around video link and table caption
    - Table anchor set to [H] for layout consistency
    - Merge split paragraphs in sections 4.2 and 5.1
2026-03-11 docs(research): actualizar validación de heartbeat con enlace a video y nuevos assets de logo
2026-03-12 docs: actualizar PIC16F1939.pdf para mostrar el resumen de pines
2026-03-12 fix(check): validar Device ID para detectar bus ICSP sin respuesta
    - Reemplaza detección por grep 'Operation Succeeded' (solo validaba el PicKit3 vía USB)
    - Usa flag -I de pk2cmd para leer el Device ID del target
    - ID 0000 indica MCLR/PGD/PGC desconectado y aborta con error
    - Compatible con múltiples chips (no valida un ID específico)
2026-03-12 chore(research/): aplicar diseño de 01_heartbeat.tex a 02_uart.tex para mantener el estandar de documentación
2026-03-12 docs: actualizar activos de hardware para la iteración 02
2026-03-12 - Actualización de registros del cajetín para la Iteración 02. - Adición de terminales UART (TX/RX) y puerto de conexión USB-TTL. - Configuración de componentes para validación de telemetría a 9600 b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
    [DomoNode_V1.kicad_sch]
2026-03-12 feat(firmware): validar telemetría bidireccional y finalizar reporte Iteración 02
    Se confirma transmisión estable de 9600 bps a 500kHz en hardware real. Reporte LaTeX actualizado con capturas de HTerm y esquemáticos. TODO: Editar y subir video 'Money Shot' usando Kdenlive (tomas d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
2026-03-13 docs: actualizar informe de la iteración 02 con validación UART y link de demostración
2026-03-13 docs: mejorar estética del README y actualizar roadmap de ingeniería
